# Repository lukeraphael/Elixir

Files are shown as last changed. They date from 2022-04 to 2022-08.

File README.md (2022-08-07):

# Elixir

The Elixir is a monoblock ergonomic mechanical keyboard. The design has been greatly inspired by the [Atreus](https://github.com/technomancy/atreus), [Sweep](https://github.com/davidphilipbarr/Sweep) and [Sofle](https://github.com/josefadamcik/SofleKeyboard) keyboards.

## Motivation

The Elixir was born out of a desire to create an 'introductory' ergonomic mechanical keyboard. Its simple and inexpensive construction reduces the time and cost required to get started. Furthermore, it was intentionally made to accomodate most common keycap sets, removing the need to obtain a niche 'ergo' keycap set.

## Features

- Powered by [QMK](https://docs.qmk.fm/#/)
- Fits many cheap standard keycap sets
  - Virtually all uniform profile sets e.g. DSA and XDA
  - Virtually all "full coverage" keycap sets
- 50 keys - just enough to accomodate to new users but few enough to allow users to experience layers, an imperative part of ergo keyboards

## Gallery

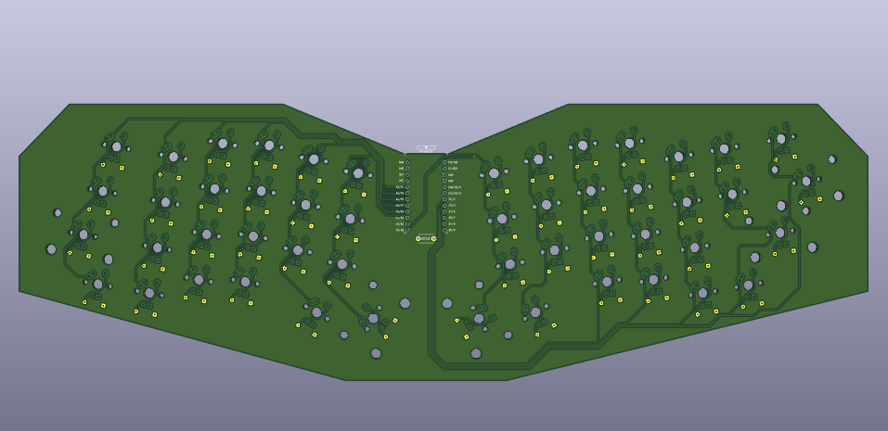
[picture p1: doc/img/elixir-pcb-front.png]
PCB


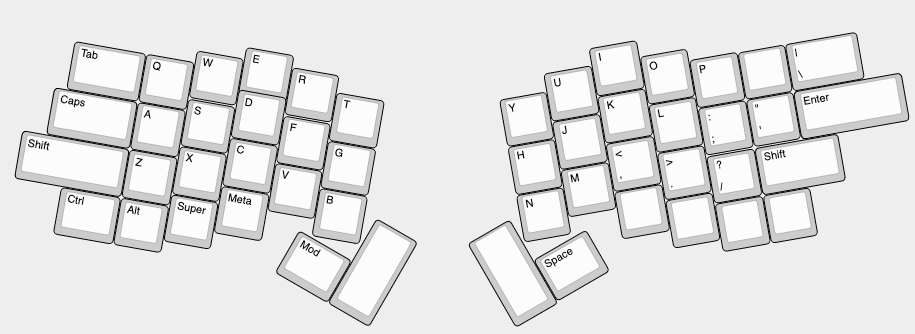
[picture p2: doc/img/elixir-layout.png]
Layout


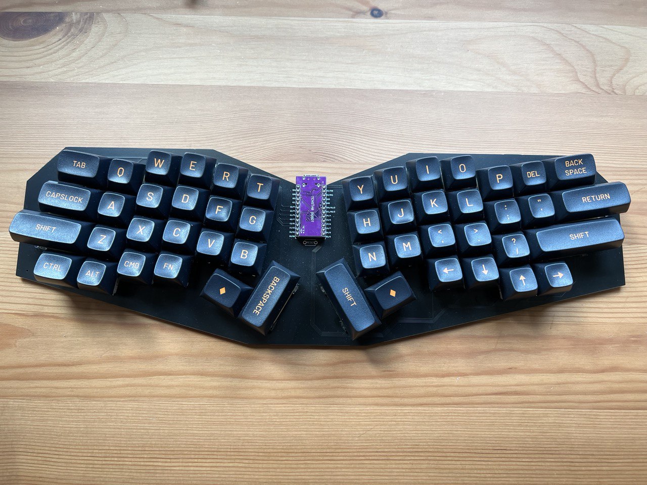
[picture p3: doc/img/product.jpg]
Product


## Install firmware
Steps:
1. Copy qmk/keyboards/elixir to your local qmk folder
2. ```qmk flash -kb elixir -km default```
3. Plug in your micro controller and set it to flashing mode (connect reset and ground pins twice)

## License



The Elixir Keyboard is licensed under [Creative Commons Attribution-NonCommercial 4.0 International License](https://creativecommons.org/licenses/by-nc/4.0).

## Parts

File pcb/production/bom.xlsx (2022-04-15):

Comment | Designator | Footprint | LCSC
D | D_TAB1,D_Q1,D_W1,D_E1,D_R1,D_T1,D_Y1,D_U1,D_I1,D_O1,D_P1,D_BSLSH1,D_CAPS1,D_A1,D_S1,D_D1,D_F1,D_G1,D_H1,D_J1,D_K1,D_L1,D_SEMIC1,D_QUOTE1,D_ENTER1,D_Z1,D_X1,D_C1,D_V1,D_B1,D_N1,D_M1,D_COMMA1,D_DOT1,D_SLASH1,D_SHIFT1,D_SUPER1,D_META1,D_BKSP1,D_CTRL1,D_ALT1,D_SPACE1,D_LEFT1,D_DOWN1,D_UP1,D_RIGHT1,D_SPACE2,D_SHIFT2,D_CTRL2,D_ALT2 | keyboard_parts:D_SOD123_axial | C81598
KEYSW | K_CAPS1 | MX_ALPS_Hybrid:MX-1.75U
KEYSW | K_CTRL1,K_ALT1 | MX_ALPS_Hybrid:MX-2U
KEYSW | K_BKSP1,K_SPACE1,K_CTRL2 | MX_ALPS_Hybrid:MX-1.25U
KEYSW | K_ENTER1,K_SHIFT2 | MX_ALPS_Hybrid:MX-2.25U
KEYSW | K_Q1,K_W1,K_E1,K_R1,K_T1,K_Y1,K_U1,K_I1,K_O1,K_P1,K_A1,K_S1,K_D1,K_F1,K_G1,K_H1,K_J1,K_K1,K_L1,K_SEMIC1,K_QUOTE1,K_Z1,K_X1,K_C1,K_V1,K_B1,K_N1,K_M1,K_COMMA1,K_DOT1,K_SLASH1,K_SUPER1,K_META1,K_LEFT1,K_DOWN1,K_UP1,K_RIGHT1,K_SPACE2,K_ALT2 | MX_ALPS_Hybrid:MX-1U
KEYSW | K_SHIFT1 | MX_ALPS_Hybrid:MX-2.75U
KEYSW | K_TAB1,K_BSLSH1 | MX_ALPS_Hybrid:MX-1.5U
SW_PUSH | SW1 | kbd:ResetSW
ProMicro | U1 | kbd:ProMicro_v3.5

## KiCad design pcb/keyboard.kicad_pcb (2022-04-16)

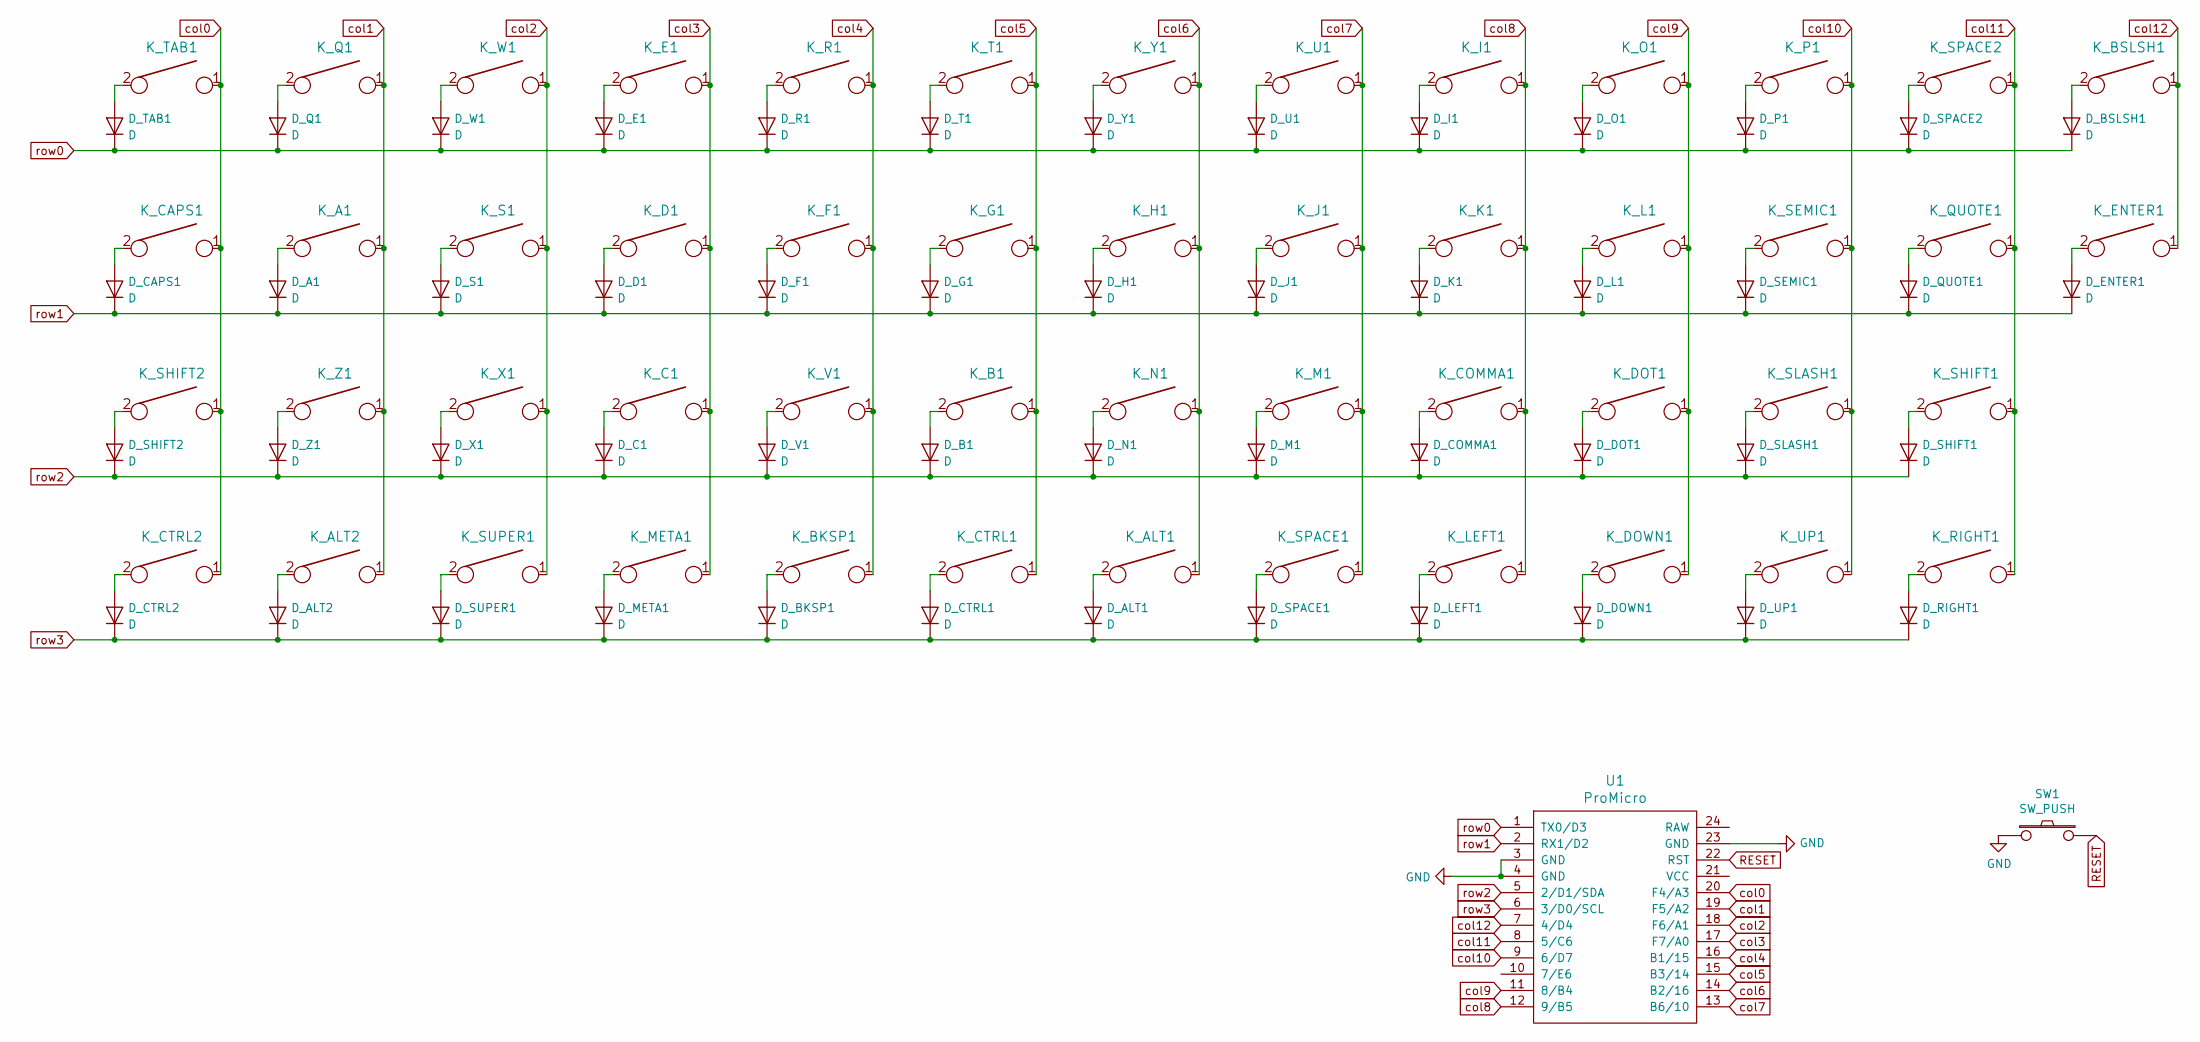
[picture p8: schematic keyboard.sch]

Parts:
D_A1: D; D_SOD123_axial
D_ALT1, D_ALT2: D; D_SOD123_axial
D_B1: D; D_SOD123_axial
D_BKSP1: D; D_SOD123_axial
D_BSLSH1: D; D_SOD123_axial
D_C1: D; D_SOD123_axial
D_CAPS1: D; D_SOD123_axial
D_COMMA1: D; D_SOD123_axial
D_CTRL1, D_CTRL2: D; D_SOD123_axial
D_D1: D; D_SOD123_axial
D_DOT1: D; D_SOD123_axial
D_DOWN1: D; D_SOD123_axial
D_E1: D; D_SOD123_axial
D_ENTER1: D; D_SOD123_axial
D_F1: D; D_SOD123_axial
D_G1: D; D_SOD123_axial
D_H1: D; D_SOD123_axial
D_I1: D; D_SOD123_axial
D_J1: D; D_SOD123_axial
D_K1: D; D_SOD123_axial
D_L1: D; D_SOD123_axial
D_LEFT1: D; D_SOD123_axial
D_M1: D; D_SOD123_axial
D_META1: D; D_SOD123_axial
D_N1: D; D_SOD123_axial
D_O1: D; D_SOD123_axial
D_P1: D; D_SOD123_axial
D_Q1: D; D_SOD123_axial
D_QUOTE1: D; D_SOD123_axial
D_R1: D; D_SOD123_axial
D_RIGHT1: D; D_SOD123_axial
D_S1: D; D_SOD123_axial
D_SEMIC1: D; D_SOD123_axial
D_SHIFT1, D_SHIFT2: D; D_SOD123_axial
D_SLASH1: D; D_SOD123_axial
D_SPACE1, D_SPACE2: D; D_SOD123_axial
D_SUPER1: D; D_SOD123_axial
D_T1: D; D_SOD123_axial
D_TAB1: D; D_SOD123_axial
D_U1: D; D_SOD123_axial
D_UP1: D; D_SOD123_axial
D_V1: D; D_SOD123_axial
D_W1: D; D_SOD123_axial
D_X1: D; D_SOD123_axial
D_Y1: D; D_SOD123_axial
D_Z1: D; D_SOD123_axial
K_A1: KEYSW; MX-1U
K_ALT1: KEYSW; MX-2U
K_ALT2: KEYSW; MX-1U
K_B1: KEYSW; MX-1U
K_BKSP1: KEYSW; MX-1.25U
K_BSLSH1: KEYSW; MX-1.5U
K_C1: KEYSW; MX-1U
K_CAPS1: KEYSW; MX-1.75U
K_COMMA1: KEYSW; MX-1U
K_CTRL1: KEYSW; MX-2U
K_CTRL2: KEYSW; MX-1.25U
K_D1: KEYSW; MX-1U
K_DOT1: KEYSW; MX-1U
K_DOWN1: KEYSW; MX-1U
K_E1: KEYSW; MX-1U
K_ENTER1: KEYSW; MX-2.25U
K_F1: KEYSW; MX-1U
K_G1: KEYSW; MX-1U
K_H1: KEYSW; MX-1U
K_I1: KEYSW; MX-1U
K_J1: KEYSW; MX-1U
K_K1: KEYSW; MX-1U
K_L1: KEYSW; MX-1U
K_LEFT1: KEYSW; MX-1U
K_M1: KEYSW; MX-1U
K_META1: KEYSW; MX-1U
K_N1: KEYSW; MX-1U
K_O1: KEYSW; MX-1U
K_P1: KEYSW; MX-1U
K_Q1: KEYSW; MX-1U
K_QUOTE1: KEYSW; MX-1U
K_R1: KEYSW; MX-1U
K_RIGHT1: KEYSW; MX-1U
K_S1: KEYSW; MX-1U
K_SEMIC1: KEYSW; MX-1U
K_SHIFT1: KEYSW; MX-2.75U
K_SHIFT2: KEYSW; MX-2.25U
K_SLASH1: KEYSW; MX-1U
K_SPACE1: KEYSW; MX-1.25U
K_SPACE2: KEYSW; MX-1U
K_SUPER1: KEYSW; MX-1U
K_T1: KEYSW; MX-1U
K_TAB1: KEYSW; MX-1.5U
K_U1: KEYSW; MX-1U
K_UP1: KEYSW; MX-1U
K_V1: KEYSW; MX-1U
K_W1: KEYSW; MX-1U
K_X1: KEYSW; MX-1U
K_Y1: KEYSW; MX-1U
K_Z1: KEYSW; MX-1U
SW1: SW_PUSH; ResetSW
U1: ProMicro; ProMicro_v3.5

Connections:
GND: SW1.1, U1.3 (GND), U1.4 (GND), U1.23 (GND)
unnamed: D_A1.2 (A), K_A1.2
unnamed: D_ALT1.2 (A), K_ALT1.2
unnamed: D_ALT2.2 (A), K_ALT2.2
unnamed: D_B1.2 (A), K_B1.2
unnamed: D_BKSP1.2 (A), K_BKSP1.2
unnamed: D_BSLSH1.2 (A), K_BSLSH1.2
unnamed: D_C1.2 (A), K_C1.2
unnamed: D_CAPS1.2 (A), K_CAPS1.2
unnamed: D_COMMA1.2 (A), K_COMMA1.2
unnamed: D_CTRL1.2 (A), K_CTRL1.2
unnamed: D_CTRL2.2 (A), K_CTRL2.2
unnamed: D_D1.2 (A), K_D1.2
unnamed: D_DOT1.2 (A), K_DOT1.2
unnamed: D_DOWN1.2 (A), K_DOWN1.2
unnamed: D_E1.2 (A), K_E1.2
unnamed: D_ENTER1.2 (A), K_ENTER1.2
unnamed: D_F1.2 (A), K_F1.2
unnamed: D_G1.2 (A), K_G1.2
unnamed: D_H1.2 (A), K_H1.2
unnamed: D_I1.2 (A), K_I1.2
unnamed: D_J1.2 (A), K_J1.2
unnamed: D_K1.2 (A), K_K1.2
unnamed: D_L1.2 (A), K_L1.2
unnamed: D_LEFT1.2 (A), K_LEFT1.2
unnamed: D_M1.2 (A), K_M1.2
unnamed: D_META1.2 (A), K_META1.2
unnamed: D_N1.2 (A), K_N1.2
unnamed: D_O1.2 (A), K_O1.2
unnamed: D_P1.2 (A), K_P1.2
unnamed: D_Q1.2 (A), K_Q1.2
unnamed: D_QUOTE1.2 (A), K_QUOTE1.2
unnamed: D_R1.2 (A), K_R1.2
unnamed: D_RIGHT1.2 (A), K_RIGHT1.2
unnamed: D_S1.2 (A), K_S1.2
unnamed: D_SEMIC1.2 (A), K_SEMIC1.2
unnamed: D_SHIFT1.2 (A), K_SHIFT1.2
unnamed: D_SHIFT2.2 (A), K_SHIFT2.2
unnamed: D_SLASH1.2 (A), K_SLASH1.2
unnamed: D_SPACE1.2 (A), K_SPACE1.2
unnamed: D_SPACE2.2 (A), K_SPACE2.2
unnamed: D_SUPER1.2 (A), K_SUPER1.2
unnamed: D_T1.2 (A), K_T1.2
unnamed: D_TAB1.2 (A), K_TAB1.2
unnamed: D_U1.2 (A), K_U1.2
unnamed: D_UP1.2 (A), K_UP1.2
unnamed: D_V1.2 (A), K_V1.2
unnamed: D_W1.2 (A), K_W1.2
unnamed: D_X1.2 (A), K_X1.2
unnamed: D_Y1.2 (A), K_Y1.2
unnamed: D_Z1.2 (A), K_Z1.2
RESET: SW1.2, U1.22 (RST)
col0: K_CAPS1.1, K_CTRL2.1, K_SHIFT2.1, K_TAB1.1, U1.20 (F4/A3)
col1: K_A1.1, K_ALT2.1, K_Q1.1, K_Z1.1, U1.19 (F5/A2)
col2: K_S1.1, K_SUPER1.1, K_W1.1, K_X1.1, U1.18 (F6/A1)
col3: K_C1.1, K_D1.1, K_E1.1, K_META1.1, U1.17 (F7/A0)
col4: K_BKSP1.1, K_F1.1, K_R1.1, K_V1.1, U1.16 (B1/15)
col5: K_B1.1, K_CTRL1.1, K_G1.1, K_T1.1, U1.15 (B3/14)
col6: K_ALT1.1, K_H1.1, K_N1.1, K_Y1.1, U1.14 (B2/16)
col7: K_J1.1, K_M1.1, K_SPACE1.1, K_U1.1, U1.13 (B6/10)
col8: K_COMMA1.1, K_I1.1, K_K1.1, K_LEFT1.1, U1.12 (9/B5)
col9: K_DOT1.1, K_DOWN1.1, K_L1.1, K_O1.1, U1.11 (8/B4)
col10: K_P1.1, K_SEMIC1.1, K_SLASH1.1, K_UP1.1, U1.9 (6/D7)
col11: K_QUOTE1.1, K_RIGHT1.1, K_SHIFT1.1, K_SPACE2.1, U1.8 (5/C6)
col12: K_BSLSH1.1, K_ENTER1.1, U1.7 (4/D4)
row0: D_BSLSH1.1 (K), D_E1.1 (K), D_I1.1 (K), D_O1.1 (K), D_P1.1 (K), D_Q1.1 (K), D_R1.1 (K), D_SPACE2.1 (K), D_T1.1 (K), D_TAB1.1 (K), D_U1.1 (K), D_W1.1 (K), D_Y1.1 (K), U1.1 (TX0/D3)
row1: D_A1.1 (K), D_CAPS1.1 (K), D_D1.1 (K), D_ENTER1.1 (K), D_F1.1 (K), D_G1.1 (K), D_H1.1 (K), D_J1.1 (K), D_K1.1 (K), D_L1.1 (K), D_QUOTE1.1 (K), D_S1.1 (K), D_SEMIC1.1 (K), U1.2 (RX1/D2)
row2: D_B1.1 (K), D_C1.1 (K), D_COMMA1.1 (K), D_DOT1.1 (K), D_M1.1 (K), D_N1.1 (K), D_SHIFT1.1 (K), D_SHIFT2.1 (K), D_SLASH1.1 (K), D_V1.1 (K), D_X1.1 (K), D_Z1.1 (K), U1.5 (2/D1/SDA)
row3: D_ALT1.1 (K), D_ALT2.1 (K), D_BKSP1.1 (K), D_CTRL1.1 (K), D_CTRL2.1 (K), D_DOWN1.1 (K), D_LEFT1.1 (K), D_META1.1 (K), D_RIGHT1.1 (K), D_SPACE1.1 (K), D_SUPER1.1 (K), D_UP1.1 (K), U1.6 (3/D0/SCL)

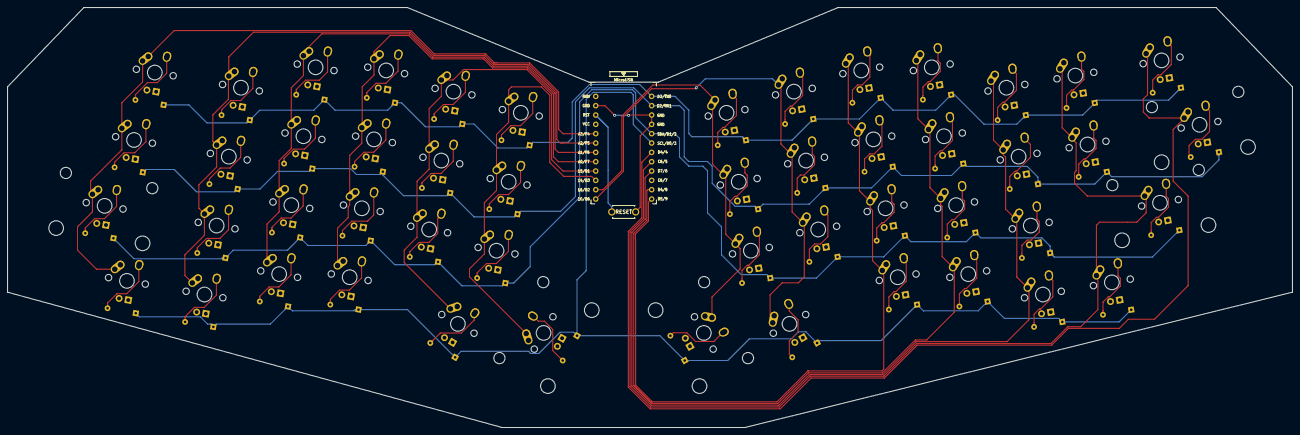
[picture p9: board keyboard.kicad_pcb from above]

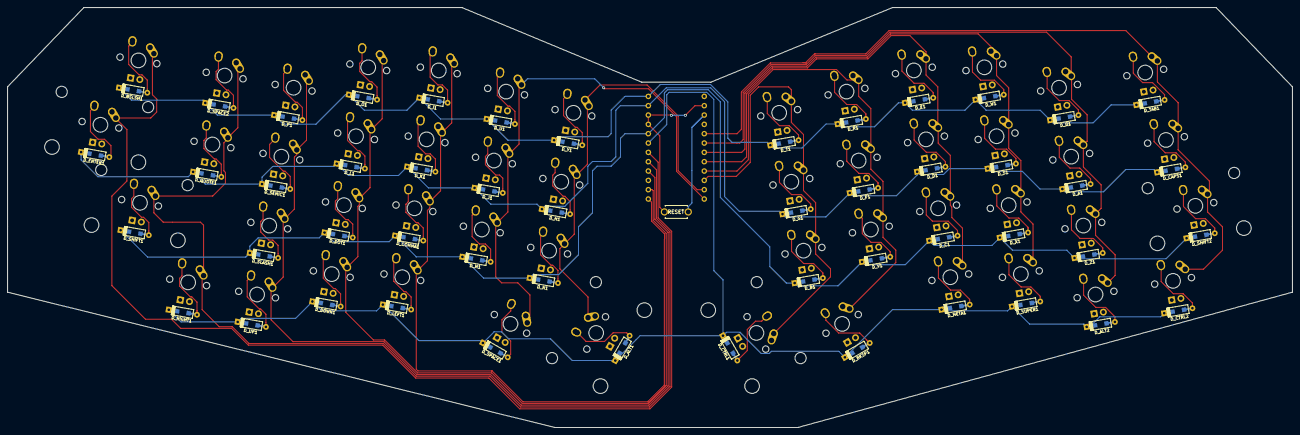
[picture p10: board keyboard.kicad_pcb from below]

Board: 2 copper layers, 349.7 x 114.3 mm, 102 parts (50 on the bottom side), 69 nets.

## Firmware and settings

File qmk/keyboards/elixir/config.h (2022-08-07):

/* Copyright 2022 Eetu Harjunpää
 *
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
 * You should have received a copy of the GNU General Public License
 * along with this program.  If not, see <http://www.gnu.org/licenses/>.
 */
#pragma once

#include "config_common.h"

/* USB Device descriptor parameter */
#define VENDOR_ID 0x4B4C
#define PRODUCT_ID 0x6060
#define DEVICE_VER 0x0001
#define MANUFACTURER lukeraphael
#define PRODUCT Elixir

/* key matrix size */
#define MATRIX_ROWS 4
#define MATRIX_COLS 13

/* key matrix pins */
#define MATRIX_ROW_PINS { D3, D2, D1, D0 }
#define MATRIX_COL_PINS { F4, F5, F6, F7, B1, B3, B2, B6, B5, B4, D7, C6, D4 }

#define DIODE_DIRECTION COL2ROW

#define MATRIX_IO_DELAY 5
#define TAP_CODE_DELAY 10

/* Debounce reduces chatter (unintended double-presses) - set 0 if debouncing is not needed */
#define DEBOUNCE 5

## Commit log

2022-04-10 removed atmega and updated schematic with promicro
    [keyboard.sch]
2022-04-11 aligned switches
    [keyboard.sch]
2022-04-11 aligned all components
    [keyboard.kicad_pcb]
2022-04-12 complete routing
    [keyboard-B_Cu.gbl, keyboard-B_Mask.gbs, keyboard-B_Paste.gbp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]
2022-04-12 add reset switch and ground zones
    [keyboard.kicad_pcb, keyboard.sch]
2022-04-12 restructure project
    [keyboard-B_Cu.gbl, keyboard-B_Mask.gbs, keyboard-B_Paste.gbp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]
2022-04-15 remove zones and reroute ground
    [bom.xlsx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]
2022-04-15 add gerbers
    [keyboard-bottom-pos.csv, keyboard-top-pos.csv]
2022-04-16 clean up routes
    [keyboard.kicad_pcb]
2022-04-16 generate gerber
    [keyboard-B_Cu.gbl, keyboard-B_Mask.gbs, keyboard-B_Paste.gbp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]

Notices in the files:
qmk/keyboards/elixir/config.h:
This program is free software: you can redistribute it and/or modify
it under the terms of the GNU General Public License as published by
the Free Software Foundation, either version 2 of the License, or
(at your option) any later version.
